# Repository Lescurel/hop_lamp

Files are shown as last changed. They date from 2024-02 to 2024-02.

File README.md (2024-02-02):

# Hop Lamp

This is the repository that contains the OpenSCAD files used to generate the
the parts of my Hop lamp (because I think it resembles a hop flower).

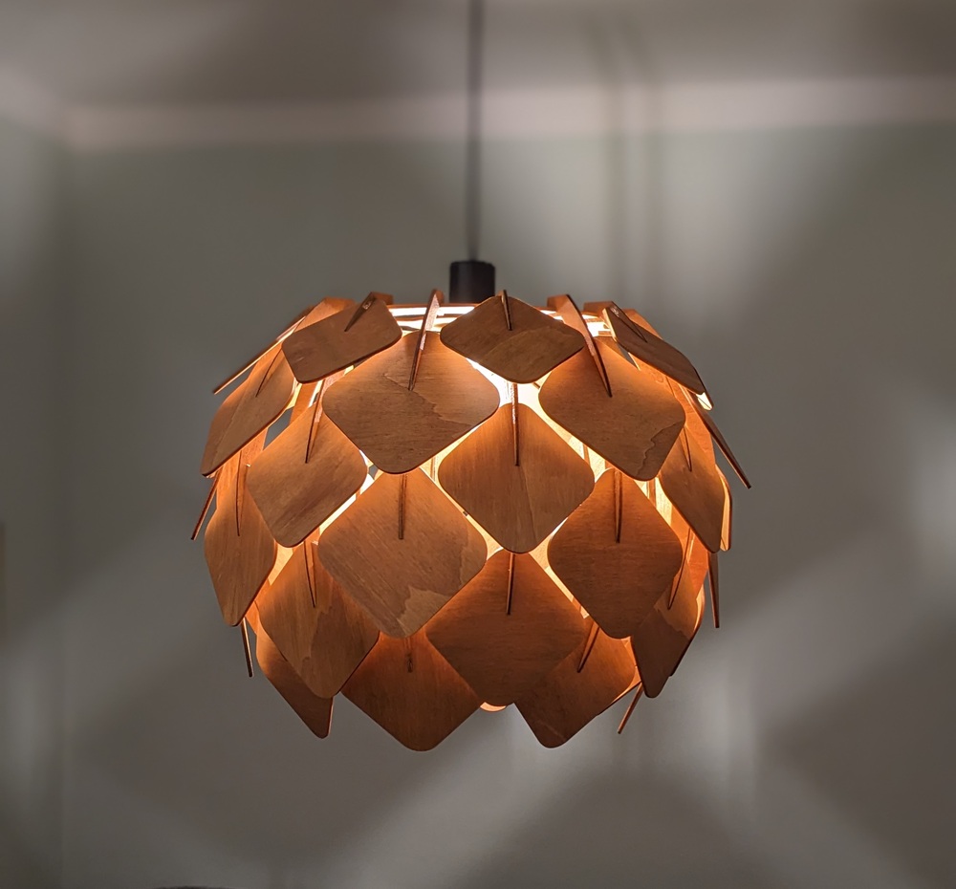
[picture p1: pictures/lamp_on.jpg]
Picture of a wooden lamp, turned on


## Details

This lamp is made entirely of plywood (except for the electricity part).
The plywood is made out of poppler, 4mm thick, stained with a teak-colored
water-based wood stain.

## Building the lamp from this repo

You can download the generated .dxf files in the Release bundle, to be used with
with a laser cutter. The lamp requires no glue nor screws. The tightness of the
parts interlocking together might depend on the thickness of your plywood and
the amount of sanding you've done to the part. You can always add a bit of
painter's tape to make the fit tighter.

The files used to make the lamp are the following:

+ `top_plate.dxf`: the upper plate of the lamp, that has a hole for the
ligthbulb holder.
+ `bottom_plate.dxf`: the lower plater of the lamp, to add some rigidity
+ `2d_arm_0.dxf`:  One of the arms. 8 are required
+ `2d_arm_1.dxf`: The other arm. 8 are required.
+ `hop_petal_XY.dxf`: where `X` is the arm number, and `Y` the position of the
petal on the arm, top to bottom. (`01`, `02` and `03` for `2d_arm_0`, and `10`,
`11` and `12` for the `2d_arm_1`). For the whole lamp, you'll need 8 of each
petal.

## Generating the files from scratch

The project requires:

- [OpenSCAD](https://openscad.org/).
- [GNU Make](https://www.gnu.org/software/make/)

Genrate all the files with make:

``` shell
$ make release
```

## Modifying the original design

You can modify the lamp relatively easily. Just pay attention that the "petals"
are not colliding with each other.
The code could use some more modularity though, and some values are hard-coded.

## Gallery

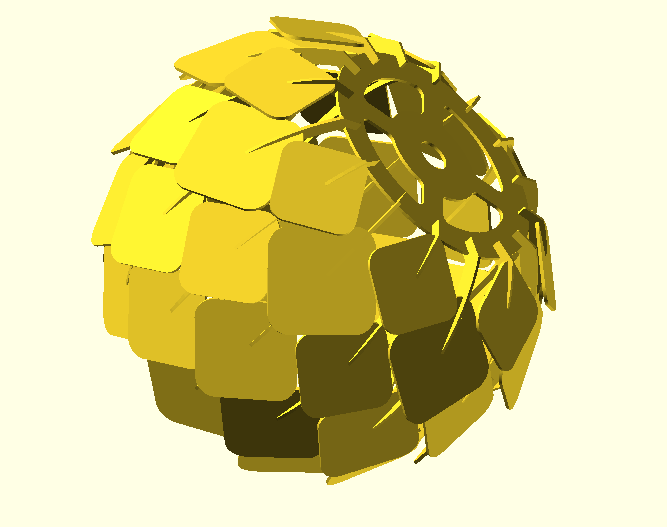
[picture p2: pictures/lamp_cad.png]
3D Model of the lamp in OpenSCAD

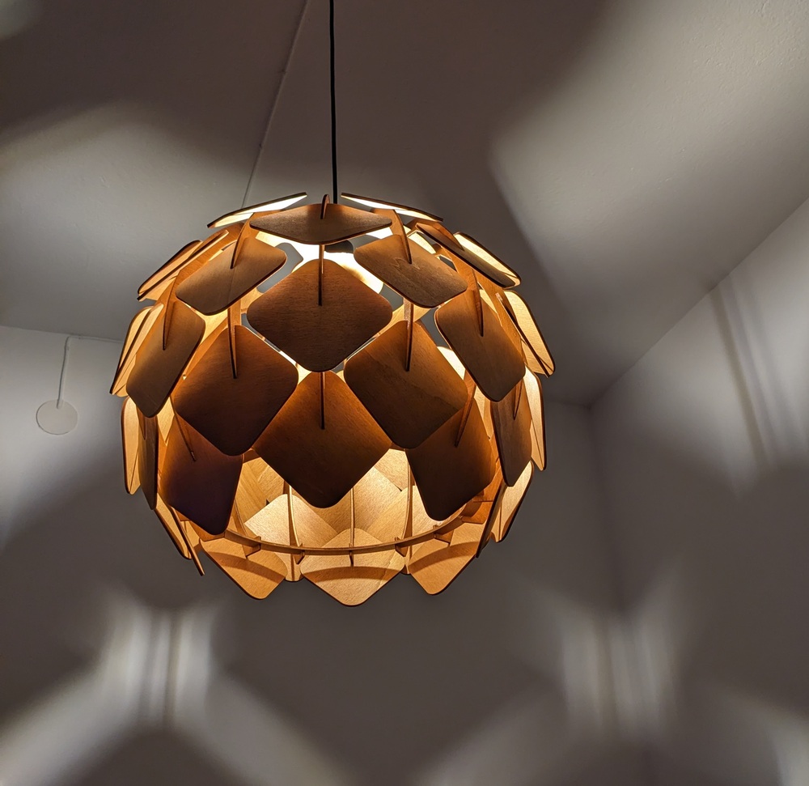
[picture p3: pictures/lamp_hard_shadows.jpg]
Other view of the lamp, with hard shadows


## License

This work is licensed under [CC-BY-SA-NC 4.0](https://creativecommons.org/licenses/by-nc-sa/4.0/)

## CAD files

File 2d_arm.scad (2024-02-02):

use <hop.scad>

plywood=4*0.9;
petal_base_angle=75;
petal_scaling_factor=0.05;
arm_rotation=-40;
petal_rotation_factor=15;

projection() 3d_arm_diff(plywood, petal_base_angle, petal_scaling_factor, arm_rotation, petal_rotation_factor);

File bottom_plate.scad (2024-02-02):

use <hop.scad>

projection()
rotate([0,90,0])
bottom_plate();

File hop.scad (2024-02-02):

$fn = 100;
lamp_hole_radius=20;
plywood = 4;

module hjortron_scale(size=120, p=4){
  diag = sqrt(2*pow(size,2));
  difference(){
  offset(r=0.2*size) offset(r=-0.2*size) 
      square(size, true);  
  rotate([0,0,45])
  translate([-diag/2+diag/16,0,0])
  square([diag/4,p], center=true);
  };
};


module attachment(size=120, thickness=4){
   rotate([0,0,-45])
    translate([0,-size/2,0])
   cube([thickness, size/4, 16], center=true);
}

module arm(r=250, w=20){
  offset(r=2,chamfer=true) offset(-2)
  union(){
    difference(){
      circle(r);
      circle(r-w); 
      square(r);
      translate([-r,-r,0]) square(r);
      translate([0,-r,0]) square(r);
    };
    // top plate connection
    translate([-r,0,0])
    rotate([0,0,-50])
    square([w*1.5,w]);
    //bottom plate connection
    translate([sin(-50)*w,r-cos(-50)*w,0])
    rotate([0,0,-50])
    square([w*1.5,w]);
  };
};

//arm();

module 3d_arm(p=4, th=70, s=0.1, t2=-40, st=15){
  
  rotate([0,0, t2]){
  union(){
  linear_extrude(p,center=true) arm();
  for(t=[0:2])
  translate([-cos(th-t*30)*250,sin(th-t*30)*250])
  rotate([90,45,(90-th)+t*30+st])
  linear_extrude(p, center=true) hjortron_scale(115*(1.-s*t));
  
};
  };
};

module 3d_arm_diff(p=4, th=70, s=0.1, t2=-40, st=15){
  difference(){
  rotate([0,0, t2]){
  difference(){
  linear_extrude(p,center=true) arm();
  for(t=[0:2])
  translate([-cos(th-t*30)*250,sin(th-t*30)*250])
  rotate([90,45,(90-th)+t*30+st])
  linear_extrude(p, center=true) hjortron_scale(115*(1.-s*t), p=p);
    };
  };
  top_plate(p=p);
  bottom_plate(p=p);
  };
};

// top plate
module top_plate(size=230, p=4){
    $fn=100;
rotate([0,-90,0])
translate([0,0,size*cos(40)]) linear_extrude(p)
    difference(){
    offset(r=-10)offset(10)
    union(){
    difference(){
        circle(size*sin(40));
        difference(){
            circle(size*sin(40)*3/4);
            circle((size*sin(40)-lamp_hole_radius)/2);
        };

    };
    for(t=[0:3]) {
    rotate([0,0,t*90])
    translate([0,size*sin(40)/2,0])    
    square([30,size*sin(40)-20],center=true);
    };
    };
    circle(lamp_hole_radius);
    for(i=[0:15]) rotate([0,0,i*360/16])translate([size*sin(40),0,0])square([15,p],center=true);
};
};


module bottom_plate(size=230, p=4){
angle=90+40;
rotate([0,-90,0])
translate([0,0,size*cos(angle)-5]) linear_extrude(p)
    difference(){
        circle(size*sin(angle));
        circle(size*sin(angle)-20);
        for(i=[0:15]) rotate([0,0,i*360/16])translate([size*sin(angle),0,0])square([15,plywood],center=true);
    };
};

union(){
top_plate();
// fruit
for(t=[0:8]){
rotate([t*(360/8),0,0])
3d_arm(4, 75, 0.05, -40, 15);
rotate([22.5+t*(360/8),0,0])
3d_arm(4, 90, -0.05, -40, 15);
};
bottom_plate();
};

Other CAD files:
hop_petal.scad
top_plate.scad

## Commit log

2023-11-29 First draft for the hjortron lamp
    SCAD files:
    + contain the top plate, bottom plate, the sides and the "scales" that
    compose the shade of the lamp
2024-02-02 All SCAD files to generate all parts of the lamp
    2d_arm is the file for genrating the armature of the lamp where the
    "petals" locks into.
    The top plate has the hole to hold the lightbulb/lamp cable.
    The bottom plate is here for structure
    [2d_arm.scad, bottom_plate.scad, hop.scad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]
2024-02-02 excluding stl/dxf/svg files
2024-02-02 better naming for variables
    [2d_arm.scad, hop_petal.scad]
2024-02-02 Makefile to create all the files to laser cut
    It's ugly, but it works. I don't really know what I'm doing
